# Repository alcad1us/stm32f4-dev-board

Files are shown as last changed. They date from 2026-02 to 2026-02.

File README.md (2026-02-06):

# STM32F4 Development Board – First PCB Design

This repository contains my first STM32-based PCB design.

The board is designed as a simple development board around an STM32F4 series microcontroller.
It includes:
- Power supply and regulation
- USB interface
- SWD programming and debugging interface
- Basic clock and decoupling circuitry

## Project Scope

This project was mainly focused on learning the **hardware design workflow**:
- Drawing the schematic
- Power and bypass (decoupling) capacitor placement
- USB D+/D− differential pair routing
- Pull-up resistor usage
- Debug interface connections
- PCB placement and routing

Rather than aiming for a production-ready board, the goal was to understand *why* certain hardware design rules exist and how they affect a real PCB.

## Visual Overview

Below are some visuals from the design process to give a quick overview without opening the design files.

### PCB Layout
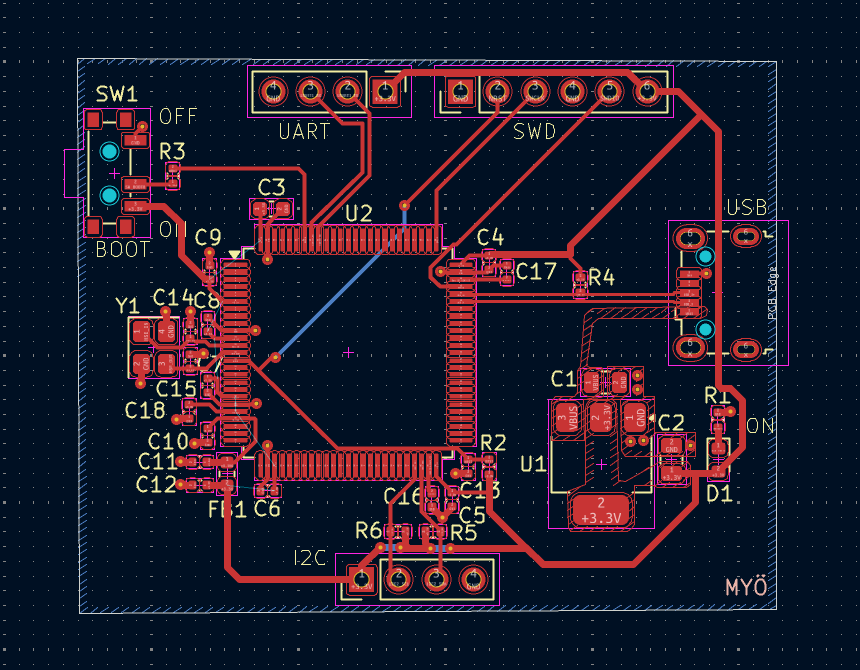
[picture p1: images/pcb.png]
PCB Layout


### 3D View
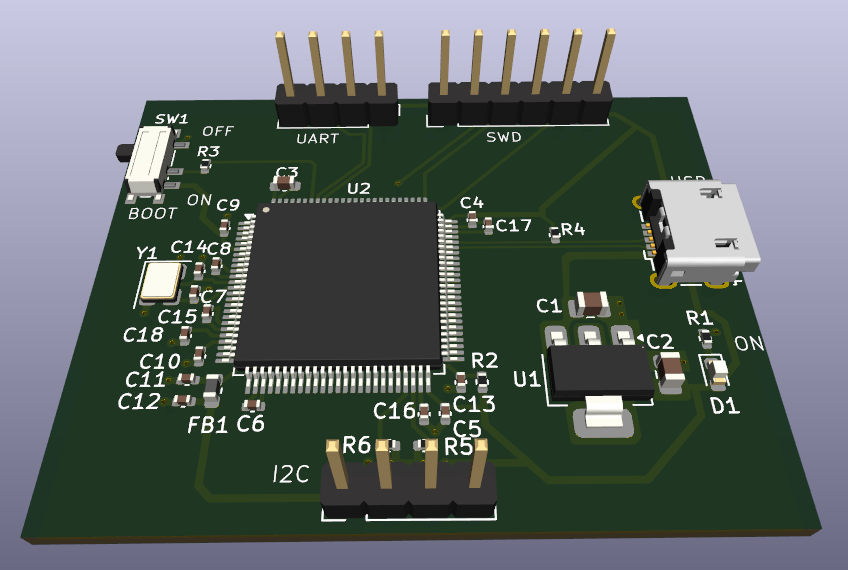
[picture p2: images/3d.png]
3D View


## Folder Structure

- pcb/ → KiCad PCB layout files
- schematic/ → KiCad schematic files
- images/ → Schematic, PCB and 3D render images

## Notes

- This is my **first PCB design**, so the focus was learning and experimentation.
- Many design decisions were made by researching, testing, and iterating.
- The project helped me clearly see the difference between theory and real-world PCB layout constraints.

## Tools Used

- KiCad
- STM32 reference documentation

## Status

Design completed.  
The project is kept as a learning reference and portfolio example.

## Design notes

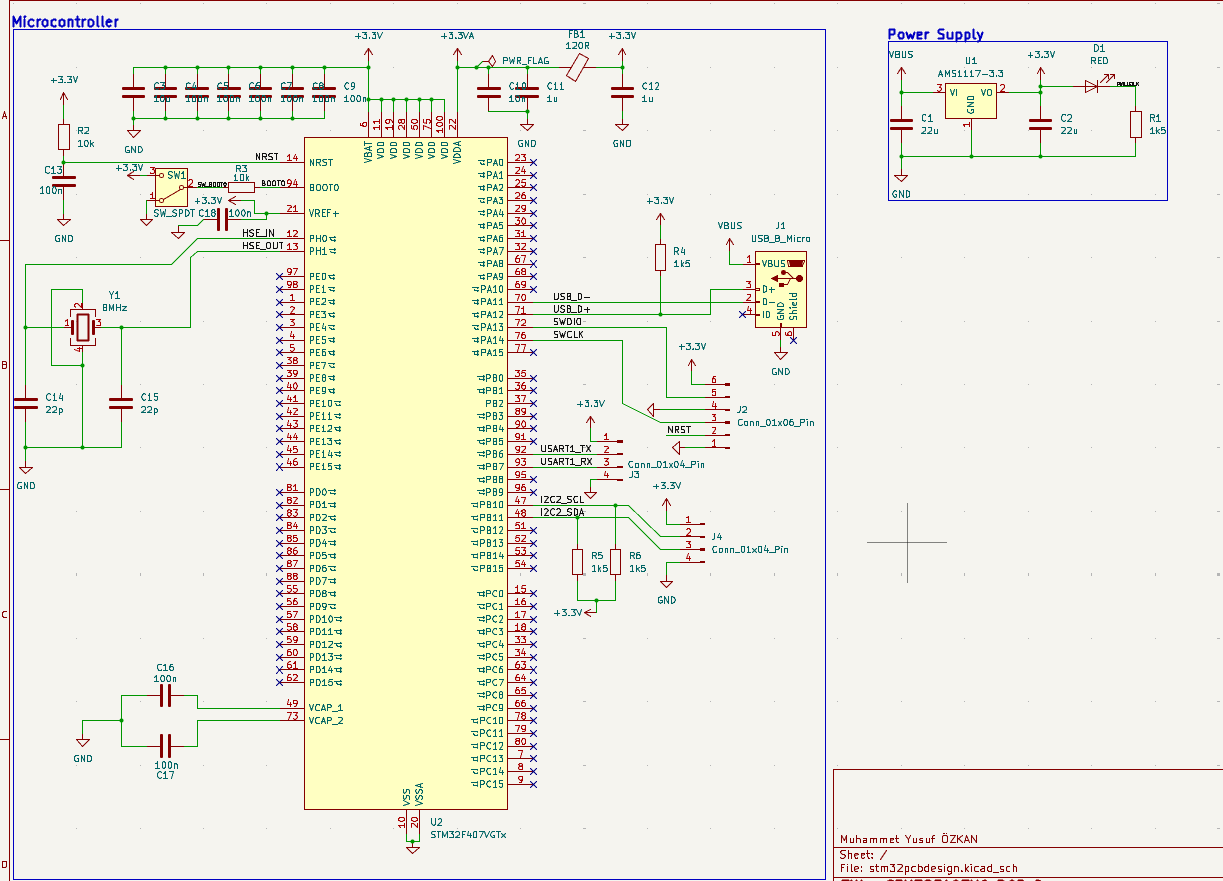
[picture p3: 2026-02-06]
images/schematic.png

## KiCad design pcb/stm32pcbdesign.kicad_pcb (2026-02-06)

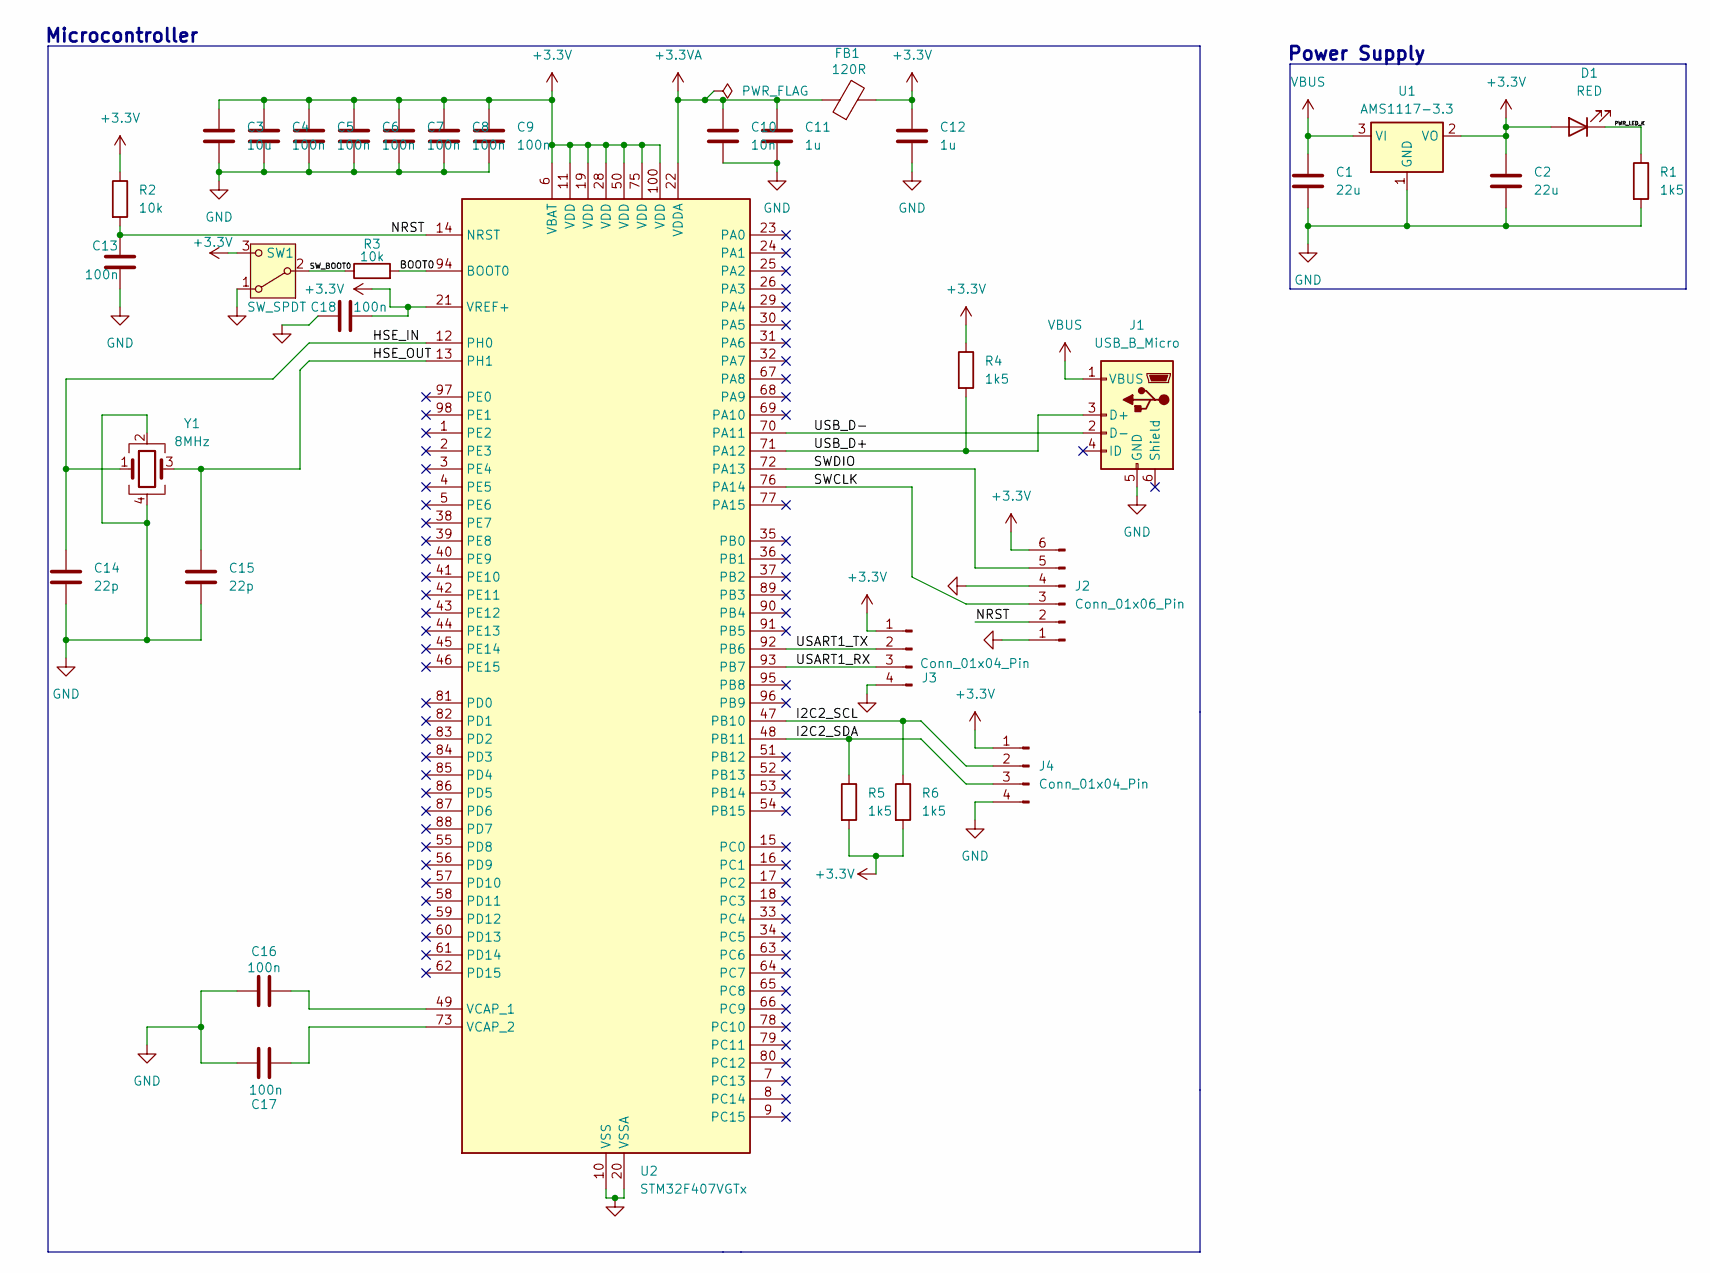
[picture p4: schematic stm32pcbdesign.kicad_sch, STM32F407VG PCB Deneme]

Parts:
C1, C2: 22u; C_0805_2012Metric
C3: 10u; C_0603_1608Metric
C4, C5, C6, C7, C8, C9, C13, C16, C17, C18: 100n; C_0402_1005Metric
C10: 10n; C_0402_1005Metric
C11, C12: 1u; C_0402_1005Metric
C14, C15: 22p; C_0402_1005Metric
D1: RED; LED_0603_1608Metric
FB1: 120R; L_0603_1608Metric
J1: USB_B_Micro; USB_Micro-B_Wuerth_629105150521
J2: Conn_01x06_Pin; PinHeader_1x06_P2.54mm_Vertical
J3, J4: Conn_01x04_Pin; PinHeader_1x04_P2.54mm_Vertical
R1, R4, R5, R6: 1k5; R_0402_1005Metric
R2, R3: 10k; R_0402_1005Metric
SW1: SW_SPDT; SW_SPDT_PCM12
U1: AMS1117-3.3; SOT-223-3_TabPin2
U2: STM32F407VGTx; LQFP-100_14x14mm_P0.5mm
Y1: 8MHz; Crystal_SMD_3225-4Pin_3.2x2.5mm

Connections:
+3.3V: C2.1, C3.1, C4.1, C5.1, C6.1, C7.1, C8.1, C9.1, C12.1, C18.2, D1.2 (A), FB1.2, J2.6, J3.1, J4.1, R2.1, R4.1, R5.2, R6.2, SW1.3 (C), U1.2 (VO), U2.6 (VBAT), U2.11 (VDD), U2.19 (VDD), U2.21 (VREF+), U2.28 (VDD), U2.50 (VDD), U2.75 (VDD), U2.100 (VDD)
+3.3VA: C10.1, C11.1, FB1.1, U2.22 (VDDA)
/BOOT0: R3.2, U2.94 (BOOT0)
/HSE_IN: C14.1, U2.12 (PH0), Y1.1
/HSE_OUT: C15.1, U2.13 (PH1), Y1.3
/I2C2_SCL: J4.2, R6.1, U2.47 (PB10)
/I2C2_SDA: J4.3, R5.1, U2.48 (PB11)
/NRST: C13.1, J2.2, R2.2, U2.14 (NRST)
/PWR_LED_K: D1.1 (K), R1.1
/SWCLK: J2.3, U2.76 (PA14)
/SWDIO: J2.5, U2.72 (PA13)
/SW_BOOT0: R3.1, SW1.2 (B)
/USART1_RX: J3.3, U2.93 (PB7)
/USART1_TX: J3.2, U2.92 (PB6)
/USB_D+: J1.3 (D+), R4.2, U2.71 (PA12)
/USB_D-: J1.2 (D-), U2.70 (PA11)
GND: C1.2, C2.2, C3.2, C4.2, C5.2, C6.2, C7.2, C8.2, C9.2, C10.2, C11.2, C12.2, C13.2, C14.2, C15.2, C16.1, C17.1, C18.1, J1.5 (GND), J2.1, J2.4, J3.4, J4.4, R1.2, SW1.1 (A), U1.1 (GND), U2.10 (VSS), U2.20 (VSSA), U2.27 (VSS), U2.74 (VSS), U2.99 (VSS), Y1.2, Y1.4
unnamed: C16.2, U2.49 (VCAP_1)
unnamed: C17.2, U2.73 (VCAP_2)
VBUS: C1.1, J1.1 (VBUS), U1.3 (VI)

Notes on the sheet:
Power Supply
Microcontroller

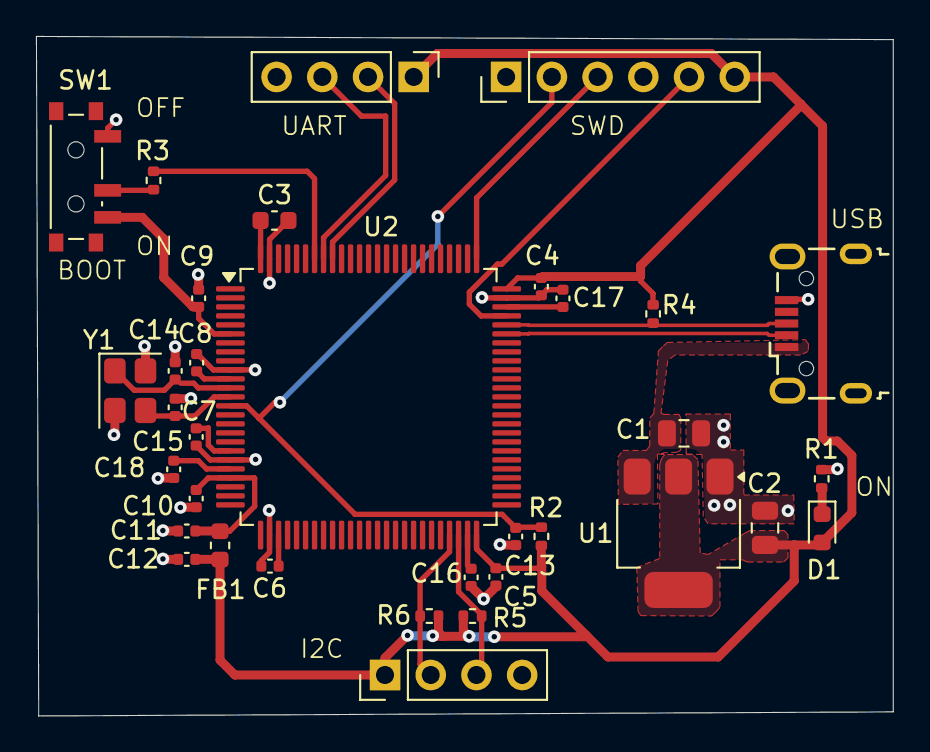
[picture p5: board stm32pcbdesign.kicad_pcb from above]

Board: 2 copper layers, 47.6 x 37.8 mm, 34 parts (0 on the bottom side), 20 nets.
